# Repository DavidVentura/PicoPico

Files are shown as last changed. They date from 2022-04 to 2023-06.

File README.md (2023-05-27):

# Pico Pico

Project to attempt to create hardware for the [Pico-8](https://www.lexaloffle.com/pico-8.php).

I'd like to eventually get full game running on a ~[Raspberry Pi Pico](https://www.raspberrypi.com/documentation/microcontrollers/raspberry-pi-pico.html)~ [ESP32](https://www.adafruit.com/product/3979)

Be aware, the code will be terrible, this is a project to learn:

* C
* SDL
* Embedded
* CMake
* Lua
    * And how to adapt / modify languages
* JIT-ting ??

This project uses [z8lua](https://github.com/DavidVentura/z8lua) to implement Pico8's Lua dialect; I've whacked the original repo to make it build 
with the Pico as a target, it was all implicit casting, which I hopefully got right.

This project also gets some "inspiration" from [tac08](https://github.com/0xcafed00d/tac08/tree/master/src) - ideas for things I don't know how to solve, and the "firmware.lua" file 
for basic implementations.

## Demo

### In emulator (SDL/rawdraw backed)

https://user-images.githubusercontent.com/3650670/209883786-df8e24eb-6469-4147-87f5-97d2407c08f9.mp4

### Celeste in ESP32

https://user-images.githubusercontent.com/3650670/168416377-bf238d62-6be6-4b70-a04c-2d60ab57a269.mp4

### In Raspberry pi Pico (port abandoned, not enough RAM)

https://user-images.githubusercontent.com/3650670/166146124-06b8b223-27b1-47ac-931f-67ba8b523d9e.mp4

### On Android

https://github.com/DavidVentura/PicoPico/assets/3650670/8b1ce7c6-c577-427d-8bed-b0ab688078c9

### On 3DS

https://github.com/DavidVentura/PicoPico/assets/3650670/648f5ae0-5fe0-4eac-8bdf-cbaad8db8e8a

## Hardware

### BOM

* 1x THT Power switch [TME](https://www.tme.eu/nl/en/details/os102011ma1qn1/slide-switches/c-k/) [PDF](https://www.tme.eu/Document/b47a7178f6dd5c46f052ff087f56764e/OS_series_DTE.pdf)
* 8x SMD button [TME](https://www.tme.eu/nl/en/details/evqq2202w/microswitches-tact/panasonic/) [PDF](https://www.tme.eu/Document/7162409d248aba412c7389d402f46025/EVQQ2series.pdf)
* 1x 10k horixontal potentiometer [TME](https://www.tme.eu/nl/en/details/r0141-2-10k/single-turn-tht-trimmers/sr-passives/) [PDF](https://www.tme.eu/Document/48eb4fb11c5e0c9b1cd467745dfbcb98/R0141-2.pdf)
* 8x SMD 10k resistor
* MAX98357 I2S audio amplifier [ALI](https://www.aliexpress.com/item/1005004280540810.html?spm=a2g0o.order_list.order_list_main.11.5b1c18020Z9uMr)
* ESP32 "Wrover" with 4MB PSRAM [Amazon](https://www.amazon.de/gp/product/B07RWHK65X/ref=ppx_yo_dt_b_asin_title_o08_s00?ie=UTF8&psc=1)
* 1.77" SPI ST7735 128x160 Display (128x128 used for game, 16px for UI, 16px padding) [ALI](https://www.aliexpress.com/item/1005003797803015.html?spm=a2g0o.order_list.order_list_main.23.5b1c18020Z9uMr)

# Goals

1. ✅ Make `hello_world` work without regressions )).
    * ~All letters are white~ (lazy palette evaluation was missing a palette indirection (screen vs draw))
1. ✅ Make `rockets` fully playable (without music // complete SFX).
    * ~Points go up too fast~ (`time()` was returning millis)
1. ✅ Create some basic automated testing.
    * Tests are at `tests/`, they run one (or a few) frames and get output.
    * Need to integrate better into the project; exclusive `ifdef` for header selection
1. Make `celeste` fully playable (without music // complete SFX)
    * ~Clouds suddenly appear~ (bad rectfill types, took uint instead of int)
    * Sometimes 2 celestes appear?? mostly on level crossings
1. Make `valdi` fully playable (without music // complete SFX)
    * ~Renders offset when looking to the left~ (wasn't calculating the sprite width accordingly in `spr()`)
    * `fillp` not implemented (background)
    * ~Super slow after a few resets?~ (`gfx_line` was missing a bounds check, overwriting the delay between frames)
1. Make `awake` fully playable (without music // complete SFX)
    * Colors are super glitched, level2 is also glitched

# Basic analysis / feasibility:

Memory requirements:

* Spritesheet, at 128x128 in size = 16KB 
    * Can move to flash
* Fontsheet, at 128x128 in size = 16KB
    * Can move to flash
* Map, at 64x128 = 8 KB
    * Can move to flash
* Flags, at 2x128 = 256B
    * Can move to flash
* Sound effects, 64x84 = 5376B (~5KB)
    * Can move to flash
* Music patterns, 64x6 = 384B
    * Can move to flash
* Front buffer 128x128/2 = 8KB (x/y position -> palette)
* Back buffer 128x128x2 = 32KB (x/y position -> color, at 16bpp)
* HUD buffer 16x128x2 = 4KB
    * Can squeeze to 8x64x2 = 1KB, or even 7 sprites (896b)
* Dedicated "Game memory" = 32KB

Totals ~130KB (of which 76KB for screen buffers and game memory have to stay).

And **most importantly** 2MB for game RAM (Lua memory). This varies based on each game, but on the PICO the 264KB ran out pretty fast. There's [this thing](https://github.com/yocto-8/yocto-8/blob/main/doc/extmem.md) to use _very slow, very cursed_ external RAM. _Some_ games 

# Performance

In RPI Pico:

Running `hello_world.lua`:

* Normal: 13ms / frame; of which:
    * Lua: ~9ms / frame
    * Copying backbuffer to screen (`uint8_t`): ~4ms / frame

* Display on 2nd core: 7.5ms / frame; of which:
    * Lua: ~7ms / frame
    * ~Copying backbuffer to screen~ happens "for free" in the other core

* Multicore + overclock to 260MHz: 3.5ms/frame

In ESP32:

Celeste takes about 9ms / frame (rendering happens on the second core), including SFX

# TODO

Immediate:

* ~Get basic rendering on the Pico~
    * ~split backends properly~
* ~Read code from p8 file instead of having split files~
* ~Implement map~
* ~Implement camera~
* ~Lua dialect~ (using z8lua)
* ~Unify the build systems (Make for pc / CMake for pico)~
* ~Pre-encode the palette colors as a RGB565 `uint16_t`; makes no sense to shift them on _every pixel write_~
* ~SFX~
* ~Measure and output the correct number of samples out of the audio buffer, currently it's a (badly) guessed number.~
* ~Get reasonable audio quality out of SFX~
* Deal with warnings when building for ESP
    * ~Figure out why they don't show up when building with SDL backend~
* ~Move hardcoded pin for ESP32 to sdkconfig~
    * Extract current values for docs WIP
* Implement more complete SFX
* Generate board captures automatically
* ~Add support for short-hand print ('?"x"' == print("x"))~
* Implement fillp https://pico-8.fandom.com/wiki/Fillp
* Lua error: bad argument #1 to 'split' (string expected, got nil)
* Lua error: bad argument #1 to 'btn' (number expected, got nil)
    * z8lua considers literal circle (🅾️) to be `nil` but not ❎

Later:

* ~Clock rate on SPI?~ set to 62.5MHz; not sure if it can go higher
* Implement flash
    * cartdata command could use it
    * carts could be stored in flash instead of static data
* Investigate pushing pixels to display via DMA
    * worth it? the second core is idle anyway
* Music
* Look at optimizing lua bytecode for "fast function calls", for "standard library"
* Use headers instead of stupid ifdefs
* Enable `-Wconversion`
* Console-based UI game
    * [Virtual keyboard](https://www.lexaloffle.com/bbs/?tid=41855) [(original, no lowercase)](https://www.lexaloffle.com/bbs/?tid=4076)
    * Wifi menu
    * Cart explorer?

# Other stuff

Resources are parsed from plaintext into a header by the `to_c.py` script, this also covers converting source code to byte-code. 
Having byte-code compiled in a pre-processing stage makes parsing faster (112ms -> 18ms for a large cart), uses less memory (bytecode 
stays in flash, not necessary to load to RAM) and enables future bytecode-level optimization

## Sound

I yoinked [zepto8's synth](https://github.com/samhocevar/zepto8/blob/master/src/synth.cpp) and converted it to `fix32`; an example SFX went 
from ~25ms to ~2ms on the ESP32.

# API Support

## Graphics

| Function | Supported | Notes |
|---|---|---|
|camera |✅ | |
|circ |✅ | |
|circfill |✅ | |
|oval |✅ | |
|ovalfill |✅ | |
|clip |✅ | |
|cls |✅ | |
|color |✅ | |
|cursor |❌ | |
|fget |✅ | |
|fillp |❌ | |
|fset |❌ | |
|line |✅ | |
|pal |⚠️ |Only "draw palette" is implemented|
|palt |✅ | |
|pget |✅ | |
|print |⚠️ |Does not automatically scroll|
|pset |✅ | |
|rect |✅ | |
|rectfill |✅ | |
|sget |✅ | |
|spr |✅ | |
|sset |✅ | |
|sspr |⚠️ | |
|tline |❌ | |

## Tables

All implemented (z8lua)

## Input

`btn` implemented

## Sound

| Function | Supported | Notes |
|---|---|---|
|sfx |⚠️ | Offset is not implemented |
|music |❌ | |

## Map

All implemented

## Memory

Not implemented

## Math

All implemented (z8lua)

## Cartridge data

| Function | Supported | Notes |
|---|---|---|
|cartdata |⚠️ | Not persistent |
|dget |⚠️ | Not persistent |
|dset |⚠️ | Not persistent |
|cstore |❌ | |
|reload |❌ | |
cartdata/dget/dset are _technically_ implemented, there's no persistence layer though.

cstore/reload are not implemented.

## Coroutines

Implemented by aliasing (z8lua)

## Strings 

Implemented (z8lua)

## Values and objects

Implemented (z8lua)

# Hardware

Build something like the [PicoSystem](https://shop.pimoroni.com/products/picosystem?variant=32369546985555) ?

# Development setup

```bash
sudo apt install cmake g++ libsdl2-dev
git submodule update --init
mkdir pc_pico && cd pc_pico
cmake -DBACKEND=PC ..
```

# Development on RP2040 (without a second Pico running OpenOCD)

Add this block to a udev rule (adjust the paths to point to this repo)
```
SUBSYSTEM=="block", ATTRS{idVendor}=="2e8a", ATTRS{idProduct}=="0003", ACTION=="add", SYMLINK+="rp2040upl%n"
SUBSYSTEM=="block", ATTRS{idVendor}=="2e8a", ATTRS{idProduct}=="0003", ACTION=="add", RUN+="/home/david/git/luatest/udev_build.sh rp2040upl%n"
```

Then having an open minicom shell 
```
sudo minicom -b 115200 -D /dev/ttyACM1
```

you can press `r` on it to reboot into mass-storage mode; which will trigger the udev rules after a second or so.

# Tests

There's a CMake backend (TEST) that you can use with `cmake -DBACKEND=TEST`; in that backend, the command `make test` will run some tests.

Some of the tests are for the internal APIs, and are written in C. Generally though, most tests should be written as p8 cartridges and placed in `tests/regression/*.p8`.

Internal API tests usually compare the output with some expected, known-good frontbuffer values (a "screenshot").
Whenever these need to change, the specific test can be re-run with the environment variable `OVERWRITE_TEST_BUF` set to any value.
This will overwrite `tests/data/buf_*.bin`. To look at these buffers, you can use the command `bin_to_png`.

```
> make test
Running tests...
Test project /Users/tati/git/PicoPico/tests_build
    Start 1: test_hello_world
1/5 Test #1: test_hello_world .................   Passed    0.03 sec
    Start 2: test_hud
2/5 Test #2: test_hud .........................   Passed    0.03 sec
    Start 3: test_menu
3/5 Test #3: test_menu ........................   Passed    0.03 sec
    Start 4: test_primitives
4/5 Test #4: test_primitives ..................   Passed    0.03 sec
    Start 5: test_regression
5/5 Test #5: test_regression ..................   Passed    0.03 sec

100% tests passed, 0 tests failed out of 5

Total Test time (real) =   0.16 sec
```

```
> ./test_regression
Testing regression_api_p8
  test_map_no_args                        [ OK]
  test_print_p8scii_color                 [ OK]

Testing regression_asan_p8
  test_sspr_same_size_is_maintained       [ OK]
  test_circ_top_left_edge                 [ OK]

Testing regression_other_p8
  test_nothing                            [ OK]
```

# Useful links

* [Easy intro to Embedding lua](https://lucasklassmann.com/blog/2019-02-02-how-to-embeddeding-lua-in-c/#example-of-error-handling)
* [Lua 5.2 Manual](https://www.lua.org/manual/5.2/manual.html)
* [Storing data in flash](https://kevinboone.me/picoflash.html?i=1)
* [Udev rule to copy build automatically](https://forums.raspberrypi.com/viewtopic.php?t=333160)
* [Getting started on basic Pico8 Gamedev](https://lukemerrett.com/getting-started-with-pico-8/)
* [GameTiger, another Pico-based console](https://github.com/codetiger/GameTiger-Console)
* [Espressif docs](https://docs.espressif.com/projects/esp-idf/en/latest/esp32/get-started/linux-macos-setup.html)
* [Importing custom 3D models into kicad](https://happyrobotlabs.com/posts/tutorials/tutorial-3d-kicad-parts-using-openscad-and-wings3d/)

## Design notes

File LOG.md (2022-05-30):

# Journal

Partly live-ramblings and partly back-filled from git log

### Wed Apr 27

I saw some news about Raspberry Pico and Pico8 on the same day and got the idea to implement Pico8-on-Pico.

First thoughts:

* Should run _some_ games without modifying the carts
* Should run on PC for easier debugging of "console" logic

To run on PC, I looked around a bit and decided to go with SDL; started following [Lazy Foo's tutorials](https://lazyfoo.net/tutorials/SDL/index.php)

Got a first basic screen with textures loading on SDL, and some colored pixels rendering on the Pico. This verison used CMake for the Pico (straight off the tutorial) and Make for PC

### Sat Apr 30

"Hello world" demo was running **really** slow, mostly because it was sending 1 byte at a time; replace ST7735 call to instead send the entire buffer directly.

Added timing on frames to "benchmark" some approaches a bit (ms resolution).

### Sun May 1

Got really annoyed at the dev cycle; to get a build onto the pico I had to:
* unplug the pico
* press bootsel while re-plugging the pico
* mount the pico
* drag & drop the new files

All of this.. to see my code crash slightly farther down the line; so I added into the input polling function, a mechanism to reset into usb mode when pressing "r" over usb-uart.. at least I could skip the "unplug, press, replug" part.  
Afterwards I also added a udev script (committed to the repo) that automatically mounts & copies the latest build over. This means that pressing "r" over UART will end up with a new build in the pico in ~8s. Need to look at OpenOCD.

Pushing a screenful of pixels takes about ~12ms with the current settings; so with logic taking ~9ms on "Hello world" demo, there's a hard limit of ~40FPS.
This sucks; games more complicated than "hello world" will spend more time on their game logic, dropping FPS down further.

Moved rendering to second core. This was _so easy_, maybe 4 lines of code; and it improved FPS dramatically (obviously -- now the rendering doesn't take time from the game cycle).
However.. the screen flashed like a maniac, having games call `cls()` while the buffer is being pushed to the screen will cause this )).

Split the screen buffer into front/backbuffer so the game can muck with the front buffer all it wants, and the copy of front->back buffers happens only on `flip()`.

Inlined `put_pixel` for an easy ~0.5ms faster frame

### Mon May 2

Add a "stdlib" to lua -- implementing pico8 special builtins

Get PC target building on CMake.

### Tue May 3

Integrate [z8lua](https://github.com/samhocevar/z8lua) into the build. It took me HOURS, as there was a lot of implicit casting that works on 64bit platforms, but not when targetting the pico.

Then spend many more hours debugging why the new Lua would work on PC and crash on Pico. Turns out `luaL_checkversion` returns errors, and the error was quite clear:

```
bad conversion number->int; must recompile Lua with proper settings
```

I'd forgotten some type casts -- I ended up changing the types for `LUA_INT32` and by extension `LUA_UNSIGNED` (this one is defined based on `LUA_INT32`). This made the interpreter work on the Pico.

This took many experiments; so after adding error handling on Lua init; I added some code to trigger "wait for re-flash" if Lua failed to init.

Another huge pain in the ass: I had a silly mistake in the `stdlib.lua` file.. and wasn't checking for errors when executing it. So the games could not access anything defined in it. Added error handling.

Still don't know how to use CMake, so added an `OPTION` to selectively build for Pico or PC. It 'works' but I need to clean the CMakeCache.txt file every time I switch.

Ran out of memory when loading "larger" games. My calculations must be off - I thought I had more space to spare. Start thinking about how to compress static data.

Remove hardcoded screen dimensions; this was the cause of ENDLESS bugs

### Wed May 4

Implement a simple RLE algorithm

|file			| initial size	| encoded	|
|---|---|---|
|artifacts/font.lua	| 16513		|4898		|
|examples/map.p8	| 3662		|807		|
|examples/btnp.p8	| 374		|375		|
|examples/movement.lua	| 287		|288		|
|examples/tennis.p8	| 21006		|3700		|
|examples/dice.p8	| 25610		|7924		|
|examples/hello\_world	| 4220		|1115		|
|total			| 68010 	|19107 (~0.3x)	|

Where you see size increase by 1 is because I always add a NULL byte at the end of the content, for easier parsing.

The algorithm is fairly simple, and strongly abuses one constraint in the input: every byte must be valid ASCII (ie: <128). This means that every byte in the input **must** have its highest bit unset.

With this in mind, the algorithm is:

* Read 1 byte
    * If highest bit is set: `count = next byte`
    * If highest bit is unset: `count = 1`
* Place the read char `count` times in output buffer
* Repeat

However! the code has to special-case the value where the repetition count is `10` (that is `\n`); as this would confuse the "read file based on newlines" algorithm. The "special" value `0xFF` is used in this case.

Realized that copying the backbuffer to screen takes 11.5ms because the SPI clock frequency is set to 30MHz. Setting it to 62.5MHz (number from `GameTiger` repo) makes the transfer take ~4ms.

# Thu May 5

I ran out of memory again, when trying to run "Rockets!". After a lot of poking around with the linker map, I realized that the static assets (cart data, font, stdlib) weren't declared as `const`! Making them `const` released ~50KB.  
I also looked for some easy memory and noticed I was allocating a static 32KB buffer for the code _text_ which is not used after Lua initializes the VM; so I made that dynamic memory and freed it after using it. Easy 32KB.
I'll probably release another 10KB later.

Struggling with the performance of `Rockets!`, seems that manually drawing rotated sprites, pixel by pixel, is _slow_. Not sure why, these ~400 calculations take ~30ms.

Will first look at converting the SPI transfers to 16bit wide (been pending for a bit..) and maybe after use the new 240x240 screen I got

# Sun May 8

Gave up on running on RP2040 after realizing there was _no way_ I could fit the promised Lua space for _game memory_ (2MB) anywhere.  
Went and got an ESP32 "WROOM32" which has 4MB (mega _bytes_) of SPIRAM (slow), but magic in the MMU makes it cache, so could be alright. Ordered one, and starting hacking on a spare ESP32 I had.

Getting the build and compiler going was a nightmare; couldn't get the magic CMake functions to include the Lua sources so it kept failing to link.

Eventually, got it going and had another nightmare: the display would randomly not turn on. Seems like it was a timing issue, as fiddling with the BLK randomly on reboot would get it going.  
When the new WROOM32 arrived, the issue mysteriously went away.

The docs on the ESP are nowhere as clear as the RP2040 docs; I kept having failures to do SPI transfers in bulk and had to chop them off in small bits. It was [right here](https://espressif-docs.readthedocs-hosted.com/projects/esp-idf/en/latest/api-reference/peripherals/spi_master.html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) in the docs though, that the default limit is _4094_ bytes. Still unsure why it wants to `malloc` its own chunk of memory per transaction, instead of letting me give it one (the backbuffer exists _for this reason_).

After this was "running" (a _lot_ of the build is hacked / chopped), I went back to the "rockets" example, as it kept having performance issues on the Pico, with ~20-30ms to draw each rotated sprite. In the ESP this is a bit faster but still very slow (~14ms).  
Biggest problem is that it does 400 inner loops _per frame, per sprite_ to draw the rotated sprites.  The only way I see something like this working is to JIT this _somehow_, but that seems _so_ hard.

Some silly performance notes:

The code for st7789, as written, would take ~500ms to render a full screen of solid color. Replacing that code with a single SPI call takes ~5-7ms. [This doc](https://austinmorlan.com/posts/embedded_game_programming_3/) helped me a bit on getting things going.

Calling `put_pixel` 50k times:

* At `-O2`: 2ms
* At `-Og`: 7ms
* At `-O0`: 10ms
* At `-Os`: 25ms

maybe `-Os` is ignoring the `inline` ?

Still can't get the SPI data transfer to be LSB to avoid having to flip endianness on the front->backbuffer copy. Can probably do it anyway when writing to the FB..

[ESP32 SPIRAM speed](https://www.esp32.com/viewtopic.php?t=13356) ~20MB/s, more if hitting the cache.

# Mon May 9

Merged ESP32 branch (breaking other targets in the process). Gave up on trying to scale up the game to my 1.33" 240x240 display; bought a 160x128 1.44" display (will have to futz around with the other driver.. again).  
But the image at least should be a lot larger & clearer.

Mostly gave up when calculated that at 40MHz, I could do over (1-bit) SPI, at MOST 40FPS, if the core did nothing but transfer data.. yet I would need to dynamically stretch the image on every frame, as there's not enough space for a 240x240x2 
framebuffer in DRAM (can use PSRAM, but that's slower). Alternative is to find and use a 8-bit SPI display, but still, not great to have to resize the image on every frame.

Thinking about audio, but that sounds super complicated so will leave that in the background and keep reading.

Found [this report](https://nymphium.github.io/pdf/opeth_report.pdf) about lua bytecode optimization and really want to look into doing something like it. Particularly lowering the cost of a function call for the "standard library"

After a couple of minutes of executing the `celeste` level; the same corruption appears on the map (a couple of black pixels); not sure why yet.

Want to configure a joystick / buttons to actually _use_ the console, but the ADC always read either 0 or 4095 and the multimeter is broken ((

# Wed May 10

Fixed the build so that all platforms can build in one go, without having to comment out `#define`s; also moved most of the code that was duplicated (`gfx_*`) to be shared, managed to delete _a bunch_ of code.

Curious about performance implications of all the current bit shifting done to render (given that each color on the palette is a `uint8_t[3]`). Starting point; in celeste, the frames take:

```
Frame avg 16200µs
Frame avg 16159µs
Frame avg 16239µs
Frame avg 16243µs
Frame avg 16170µs
Frame avg 16144µs
Frame avg 16311µs
Frame avg 16240µs
```
(Average: 16213)

Moving average, over 100 frames.

And after changing the palette lookup per pixel:

```
Frame avg 13876µs
Frame avg 13849µs
Frame avg 13963µs
Frame avg 14121µs
Frame avg 13989µs
Frame avg 13923µs
Frame avg 13892µs
```
(Average: 13944)

16% faster!! that's a nice, easy win.

# 13 May

Got SFX working! Struggled to understand the basics of synths but [this video](https://www.youtube.com/watch?v=OSCzKOqtgcA) helped quite a bit.

Getting SDL going also took a while; combination of sample rates and endianness blasted my ears more than necessary.

When the emulator sounded OK, I ran it on the ESP32 without any output configured and saw that the simplest SFX took ~25ms to calculate (sure, the sound lasts like 400ms, but I don't want 10% of the CPU time to go to SFX!).

I know the ESP32 has an FPU, which means floating point calculations are not _terribly_ slow, but they are not as fast as integer arithmethic; so made some optimizations: turns out `fmodf(advance, 1.f)` takes _8_ extra milliseconds than  `advance - truncf(advance)` (over ~11 thousand calls).  This already brought ~25ms to ~17ms.  Moved quite some constants to be static and some calculations out from the inner loop, and the execution time dropped to ~4.5ms(!)

Still, the [Performance guide](https://docs.espressif.com/projects/esp-idf/en/latest/esp32/api-guides/performance/speed.html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) on ESP32 says

>  Even though ESP32 has a single precision hardware floating point unit, floating point calculations are always slower than integer calculations. If possible then use fixed point representations [...]

and I already am linking `fix32` for Lua.. so converted the synth to use fixed point and that made it at least twice as fast (down to ~2ms).

# 14 May

Rewrote the sounds pipeline -- it used to generate ALL the samples for an SFX on demand, and fill HUGE buffers with it.  
Now, based on a lot of reading (which is greatly summarized [here](https://atomic14.com/2021/04/20/esp32-i2s-dma-buf-len-buf-count.html)) I've changed the pipeline to only generate samples on demand (when the DMA buffers are empty) -- currently that is ~20ms worth of audio. This simplified the code a lot, and now it actually works without pops

# 17 May

Start looking at Lua performance overhead:

Benchmark code:
```lua
start = t()
for i=1,32000 do
      noop(i)
end
endt = t()
printh("32k x noop took ".. endt-start)
```
- 32.000 noop calls (takes 1 number and returns it) = 122ms

meaning, 1.000 calls = 3.8ms. **This caps the calls per frame at 8684 without doing any work**.

Per iteration; the bytecode looks like

```
5	[2]	GETTABUP 	4 0 -3	; _ENV "noop"
6	[2]	MOVE     	5 3
7	[2]	CALL     	4 2 1
```

Same code in C (with -O0) takes ~6ms:

```c
#pragma GCC push_options
#pragma GCC optimize ("O0")
int _noop(int arg) {
    return arg;
}
void bench_me() {
    uint32_t bstart = now();
    int res = 0;
    for (uint16_t i=0; i<32000; i++) {
        res = _noop(5);
    }
    printf("Benchmark took %d; result is %d\n", now()-bstart, res);
}
#pragma GCC pop_options
```

Approximately, 20x faster is the maximum we can get to.

# 18 May

On first pass of ["Fast C Calls"](https://github.com/DavidVentura/z8lua/commit/201aa808ca1e0b0529a6d9af0c80307fec263d92):

> 32k x noop took 94ms

1000 calls = 2.9ms; new code takes 77% of the time as the previous one;

the bytecode hasn't changed; so 

```
5	[2]	GETTABUP 	4 0 -3	; _ENV "noop"
6	[2]	MOVE     	5 3
7	[2]	CALL     	4 2 1
```

this way, `noop` is _still looked up for each call_; as the function tag is embedded in the function itself (which is stored in `_ENV`)

this is faster, yes, but not _really_ fast

Calling a function that does a _small_ amount of work:

```lua
start = t()
for i=1,32000 do
      fast_floor(i+0.5)
end
endt = t()
printh("32k x fast_floor took ".. endt-start)

start = t()
for i=1,32000 do
      flr(i+0.5)
end
endt = t()
printh("32k x flr took ".. endt-start)

```

> 32k x fast_floor took 99ms
> 32k x flr took 145ms

Not really sure about these results.. the fast call went up by 5ms (I assume, calculating how to floor the number), but the regular call doesn't take 5 ms more than the slow noop.. takes 23ms more.

I think the real improvement for this would be to add a new opcode (ie: FASTCALL) that'd embed the function ID in a byte or something. I only want to "accelerate" a handful of calls (<30) so capping at 255 is not a problem.

This all kinda started by looking again at `Rockets!` which used to take ~30ms to draw each sprite (it calculates rotation _every frame_)

With the "regular" `flr` calls, drawing 5 sprites consistently takes 71ms, and with the fast calls it consistently takes 65ms. It's a nice 9% win, but still _really_ far from hitting the <30ms mark to make the game playable.

This is the function that's so slow:

```lua
function spr_r(s,x,y,a,w,h)
	sw=(w or 1)*8
	sh=(h or 1)*8
	sx=(s%8)*8
	sy=flr(s/8)*8
	x0=flr(0.5*sw)
	y0=flr(0.5*sh)
	a=a/360
	sa=sin(a)
	ca=cos(a)
	for ix=sw*-1,sw+4 do
		for iy=sh*-1,sh+4 do
			dx=ix-x0
			dy=iy-y0
			xx=flr(dx*ca-dy*sa+x0)
			yy=flr(dx*sa+dy*ca+y0)
			if (xx>=0 and xx<sw and yy>=0 and yy<=sh-1) then
				pset(x+ix,y+iy,sget(sx+xx,sy+yy))
			end
		end
	end
end
```

`sw` and `sh` are always 8; so both loops go from -12 to 12 (=576 iterations for the inner loop). This is _per sprite_ and up to 5 sprites can be live at any point in time.

If you know about lua performance, you already know what the _biggest_ problem is here, but it is very obvious when looking at bytecode; this is the inner loop:

```
	50	[569]	GETTABUP 	14 0 -8	; _ENV "x0"
	51	[569]	SUB      	14 9 14
	52	[569]	SETTABUP 	0 -18 14	; _ENV "dx"
	53	[570]	GETTABUP 	14 0 -10	; _ENV "y0"
	54	[570]	SUB      	14 13 14
	55	[570]	SETTABUP 	0 -19 14	; _ENV "dy"
	56	[571]	GETTABUP 	14 0 -7	; _ENV "flr"
	57	[571]	GETTABUP 	15 0 -18	; _ENV "dx"
	58	[571]	GETTABUP 	16 0 -14	; _ENV "ca"
	59	[571]	MUL      	15 15 16
	60	[571]	GETTABUP 	16 0 -19	; _ENV "dy"
	61	[571]	GETTABUP 	17 0 -12	; _ENV "sa"
	62	[571]	MUL      	16 16 17
	63	[571]	SUB      	15 15 16
	64	[571]	GETTABUP 	16 0 -8	; _ENV "x0"
	65	[571]	ADD      	15 15 16
	66	[571]	CALL     	14 2 2
	67	[571]	SETTABUP 	0 -20 14	; _ENV "xx"
	68	[572]	GETTABUP 	14 0 -7	; _ENV "flr"
	69	[572]	GETTABUP 	15 0 -18	; _ENV "dx"
	70	[572]	GETTABUP 	16 0 -12	; _ENV "sa"
	71	[572]	MUL      	15 15 16
	72	[572]	GETTABUP 	16 0 -19	; _ENV "dy"
	73	[572]	GETTABUP 	17 0 -14	; _ENV "ca"
	74	[572]	MUL      	16 16 17
	75	[572]	ADD      	15 15 16
	76	[572]	GETTABUP 	16 0 -10	; _ENV "y0"
	77	[572]	ADD      	15 15 16
	78	[572]	CALL     	14 2 2
	79	[572]	SETTABUP 	0 -21 14	; _ENV "yy"
	80	[573]	GETTABUP 	14 0 -20	; _ENV "xx"
	81	[573]	LE       	0 -22 14	; 0.0 -
	82	[573]	JMP      	0 24	; to 107
	83	[573]	GETTABUP 	14 0 -20	; _ENV "xx"
	84	[573]	GETTABUP 	15 0 -1	; _ENV "sw"
	85	[573]	LT       	0 14 15
	86	[573]	JMP      	0 20	; to 107
	87	[573]	GETTABUP 	14 0 -21	; _ENV "yy"
	88	[573]	LE       	0 -22 14	; 0.0 -
	89	[573]	JMP      	0 17	; to 107
	90	[573]	GETTABUP 	14 0 -21	; _ENV "yy"
	91	[573]	GETTABUP 	15 0 -4	; _ENV "sh"
	92	[573]	SUB      	15 15 -2	; - 1.0
	93	[573]	LE       	0 14 15
	94	[573]	JMP      	0 12	; to 107
	95	[574]	GETTABUP 	14 0 -23	; _ENV "pset"
	96	[574]	ADD      	15 1 9
	97	[574]	ADD      	16 2 13
	98	[574]	GETTABUP 	17 0 -24	; _ENV "sget"
	99	[574]	GETTABUP 	18 0 -5	; _ENV "sx"
	100	[574]	GETTABUP 	19 0 -20	; _ENV "xx"
	101	[574]	ADD      	18 18 19
	102	[574]	GETTABUP 	19 0 -6	; _ENV "sy"
	103	[574]	GETTABUP 	20 0 -21	; _ENV "yy"
	104	[574]	ADD      	19 19 20
	105	[574]	CALL     	17 3 0
	106	[574]	CALL     	14 0 1
```

The issue here are all those `GETTABUP` (`get table upvalue`) which are looking up the _global variables_ in every call. Usually, the way to have this work faster is by declaring each variable `local` so they'll be in the function's registers. By changing all the variables to `local`, this is the generated bytecode

```
	36	[569]	SUB      	23 18 10
	37	[570]	SUB      	24 22 11
	38	[571]	GETTABUP 	25 0 -3	; _ENV "flr"
	39	[571]	MUL      	26 23 14
	40	[571]	MUL      	27 24 13
	41	[571]	SUB      	26 26 27
	42	[571]	ADD      	26 26 10
	43	[571]	CALL     	25 2 2
	44	[572]	GETTABUP 	26 0 -3	; _ENV "flr"
	45	[572]	MUL      	27 23 13
	46	[572]	MUL      	28 24 14
	47	[572]	ADD      	27 27 28
	48	[572]	ADD      	27 27 11
	49	[572]	CALL     	26 2 2
	50	[573]	LE       	0 -10 25	; 0.0 -
	51	[573]	JMP      	0 15	; to 67
	52	[573]	LT       	0 25 6
	53	[573]	JMP      	0 13	; to 67
	54	[573]	LE       	0 -10 26	; 0.0 -
	55	[573]	JMP      	0 11	; to 67
	56	[573]	SUB      	27 7 -1	; - 1.0
	57	[573]	LE       	0 26 27
	58	[573]	JMP      	0 8	; to 67
	59	[574]	GETTABUP 	27 0 -11	; _ENV "pset"
	60	[574]	ADD      	28 1 18
	61	[574]	ADD      	29 2 22
	62	[574]	GETTABUP 	30 0 -12	; _ENV "sget"
	63	[574]	ADD      	31 8 25
	64	[574]	ADD      	32 9 26
	65	[574]	CALL     	30 3 0
	66	[574]	CALL     	27 0 1
```

With this change, rendering 5 sprites goes from the ("optimized") 65ms/frame to **29ms/frame**. 21 extra lookups * 576 inner loops = 12096 calls.. which acording to my original benchmarking (if these were function calls) is ~45ms.

So, maybe optimizing opcodes for fastcalls is not the thing that will bring the biggest gains; maybe a bytecode optimizer would be better.

Performing some manual optimizations in the lua code (declaring a local copy of `pset` `sget` `flr` and lifting calculations outside the inner loop) brought the frame time to **23ms**; a 26% improvement; and _almost_ perfectly playable.

TODO: fastcall `sget` and `pset` to test the impact (12k calls each ?)

Interesting optimizations:

* Localizing global accesses (`sin` shouldn't be loaded from `_ENV`)
* Fast builting calls (`sin` should be called cheaply)
* [Loop hoisting](https://en.wikipedia.org/wiki/Loop-invariant_code_motion)

# 20 May

Still going on about performance; now on trig functions:

Baseline

> 32k x c sin floating took 548ms

Optimizing calls into the "regular fastcalls" (ie: still looking up via _ENV on every call)

> 32k x fast sin floating took 718ms
> 32k x slow sin floating took 735ms

This makes 32k calls, 20ms faster.. in practice this is not going to make a difference

Still struggling to figure out how to emit bytecode that's aware of the builtins

Optimizing `sin`:

Using [fixed point calculations](https://www.nullhardware.com/blog/fixed-point-sine-and-cosine-for-embedded-systems/) for `sin`:

> 32k x c sin fixed 	  took  50ms
> 32k x fast sin fixed 	  took 107ms
> 32k x slow sin fixed 	  took 135ms
> 32k x slow sin floating took 735ms

Now this is _a lot_ faster! ~7x faster `sin` / `cos` calls

# 22-23 May

Wrote/Adapted a bytecode parser in python

# 25 May

Thinking about bytecode optimization, tried to write a "too-hard" optimization from the start and failing.

Easy optimizations to start with:

* Make all globals, "local scoped globals"
    * Declare them `local` at the root chunk
    * Adjust upvals on all functions
    * Replace {GET,SET}TABUP with {GET,SET}UPVAL
* Remove unused constants (that will happen when removing {GET,SET}TABUP)
* Remove unnecessary loads when there's no change in the registers
    * ```
	[018] [32]   GETTABUP : 6 0 -7; _ENV "flr"
	[019] [32]   GETTABUP : 7 0 -1; _ENV "sw"
	[020] [32]        MUL : 7 -9 7; (L)R(7) := K(9) * R(7)
	[021] [32]       CALL : 6 2 2
	[022] [32]   SETTABUP : 0 -8 6; _ENV "x0"
	[023] [33]   GETTABUP : 6 0 -7; _ENV "flr"
     ```
     in this case,  `GETTABUP : 6 0 -7; _ENV "flr"` is executed twice, and nothing writes to `R(6)` between them

# 28 May

Spent a long while getting a MAX98357 chip (I2S audio) to work. I kept getting "buzzing" sound instead of anything, even when memory dump of the waveforms gave me the same numbers as what I'd get on my SDL backend.

Mucked around with endianness; channel format; sample depth; timing. No dice. In the end, It's because I was using a 0.5W speaker with a 3W (max) amplifier. A 160Ohm resistor in series with the speaker made it work perfectly.

# 30 May

I am starting to think optimizing the bytecode will be fruitless; the "problematic" calculation-heavy routine from Rockets! still takes up to 30ms/frame after optimization. I manually converted that function to be a regular C function
and the time per frame dropped to 5ms; where 3.5-4 of those are spent drawing the map.

Got a _very bad, very simplistic_ code emitter for a Lua parser. Will see how it goes; main concerns are:

* Variable scoping
* Closures
* Co-routines
* Dynamic types

but it seems more "tractable" to let GCC optimize code, and a lot easier to get started. Although it's a lot more work to get a game into a playable state.

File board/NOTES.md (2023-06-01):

v2 issues:
- RX/TX to usb-serial chip inverted

v2 notes:
- "wrong" footprint for display
  - used the "connector" footprint but soldered...
  - should've used the solderable pinout (wider) or a connector..
- audio:
  - using resistor instead of voltage divider
  - shoddy audio idea of soldering pcb on pcb
  - direct soldering MAX98357 SKETCH
  - volume control (potentiometer) too far from edge
  - volume control footprint loose, no metal on mechanical holes
- testpoints very small
- labels very small
- battery JST different
- usb-micro not usb-c
- "jumpers" for display fuckups:
    - too close (side-by-side)
	- too large footprint for easy bridging? (MB)
- BUY STENCIL

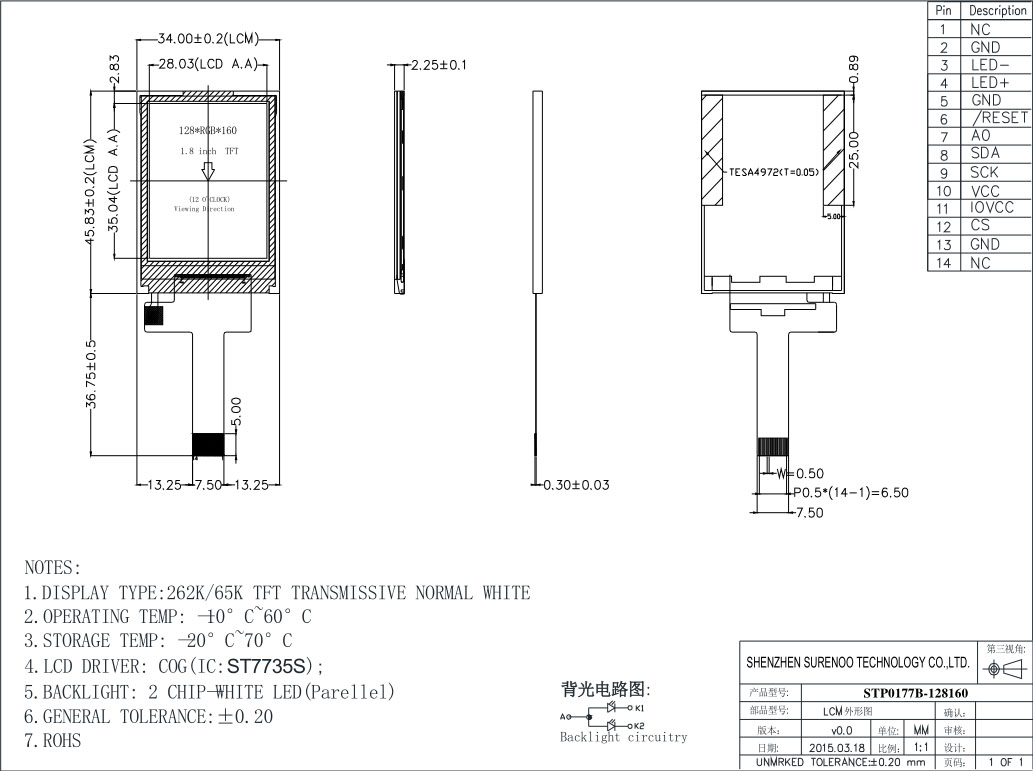
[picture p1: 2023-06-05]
board/datasheets/display.jpg

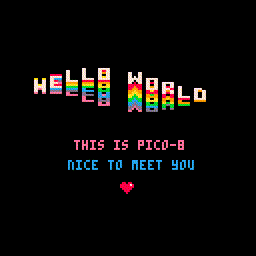
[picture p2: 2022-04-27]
artifacts/hello_world.gif

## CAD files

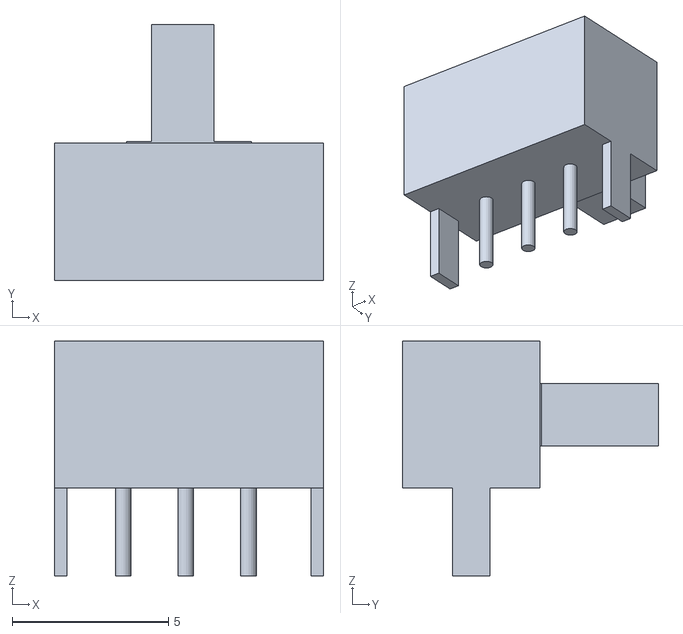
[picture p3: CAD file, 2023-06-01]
board/3dmodels/power_switch.stl
8.60 x 8.20 x 7.50

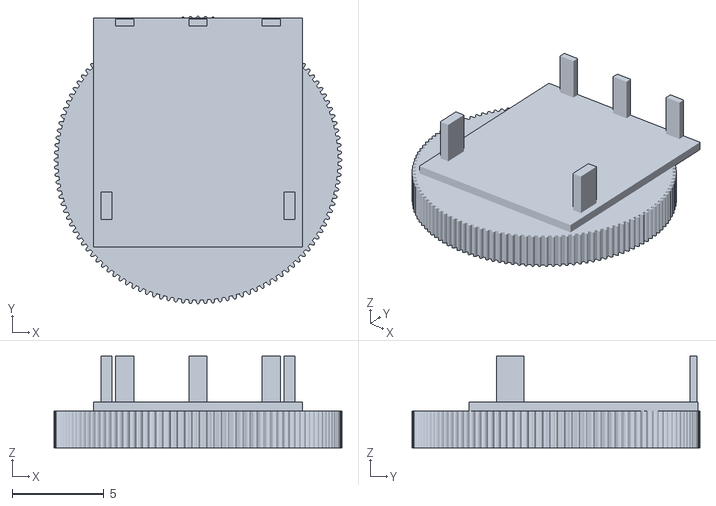
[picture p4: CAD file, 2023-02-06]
board/3dmodels/volumewheel.stl
15.7 x 15.7 x 5.00

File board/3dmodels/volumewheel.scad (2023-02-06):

pi=3.141592;
$fn=16;
module tooth(pitch){
	translate([0,0,0])scale([2,1,1])circle(pitch/2,$fn=24);
	}

module gear2d(teeth,pitch,clearance){
		union(){
			translate([0,0,0])circle(((pitch*teeth)/pi)-clearance,$fn=100);
			for(n=[1:teeth]){
				rotate([0,0,(360/teeth)*n])
				translate([(pitch*teeth)/pi,0,0])tooth(pitch*1.1);
			}
		}
	}
    
    
module pin(factor=1) {
PIN_HEIGHT=2.5;
color("silver")
cube([1*factor, 0.4*factor, PIN_HEIGHT], center=true);
}

GEAR_HEIGHT=2;
color("black")
difference() {
linear_extrude(height=GEAR_HEIGHT, center=true,convexity=10,twist=0,slices=1)
gear2d(teeth=120,pitch=0.2,clearance=0);
cylinder(h=2.1, r=2, center=true);
}

// base
color("silver")
translate([0, 1.5, 1.25])
cube([11.4, 12.5, 0.5], center=true);

// mechanical
translate([-5, -2.5, 2.75])
rotate([0,0,90])
pin(factor=1.5);


translate([5, -2.5, 2.75])
rotate([0,0,90])
pin(factor=1.5);

// pins

translate([-4, 7.5, 2.75])
pin();
translate([0, 7.5, 2.75])
pin();
translate([4, 7.5, 2.75])
pin();

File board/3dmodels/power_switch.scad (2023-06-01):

$fn=20;
PIN_HEIGHT=2.8;
PIN_SPACING=2;

// main body
color("silver")
cube([8.6, 4.4, 4.7], center=true);

// switch
color("black")
translate([1-2*$t, 4, 0])
rotate([0, 90, 0])
cube([2.0, 4.0, 2.0], center=true);

// switch displacement area
color("gray")
translate([0, 2.2, 0])
rotate([0, 90, 0])
cube([2.0, 0.1, 4.0], center=true);

// mechanical pins
color("darkgray")
translate([-8.6/2+0.4/2, 0, -(PIN_HEIGHT/2)-(4.7/2)])
cube([0.4, 1.2, PIN_HEIGHT], center=true);

color("darkgray")
translate([8.6/2-0.4/2, 0, -(PIN_HEIGHT/2)-(4.7/2)])
cube([0.4, 1.2, PIN_HEIGHT], center=true);

// electrical pins
color("darkgray")
translate([-8.6/2+0.4/2+PIN_SPACING*1, 0, -(PIN_HEIGHT/2)-(4.7/2)])
cylinder(r=0.25, h=PIN_HEIGHT, center=true);
color("darkgray")
translate([-8.6/2+0.4/2+PIN_SPACING*2, 0, -(PIN_HEIGHT/2)-(4.7/2)])
cylinder(r=0.25, h=PIN_HEIGHT, center=true);

color("darkgray")
translate([-8.6/2+0.4/2+PIN_SPACING*3, 0, -(PIN_HEIGHT/2)-(4.7/2)])
cylinder(r=0.25, h=PIN_HEIGHT, center=true);

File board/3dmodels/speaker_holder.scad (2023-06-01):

$fn=35;
OUT_SPKR_DIAM=10;
IN_SPKR_DIAM=8;
PAD=2;

difference() {
    cube([OUT_SPKR_DIAM+PAD, OUT_SPKR_DIAM+PAD, 0.5], center=true);
    
    translate([0, 0, 0.151])
    cylinder(h=0.2, r=OUT_SPKR_DIAM/2, center=true);
    cylinder(h=0.51, r=IN_SPKR_DIAM/2, center=true);
    
    for(x= [-1, 1]) {
        for(y= [-1, 1]) {
            translate([(OUT_SPKR_DIAM+PAD/2)/2*x-x, (OUT_SPKR_DIAM+PAD/2)/2*y-y, 0])
            cylinder(h=1.1, r=1, center=true);
        }
    }
}

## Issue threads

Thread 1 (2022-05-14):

Can you please share the reasons for moving from RP2040 Chip to ESP32

codetiger, 2022-05-14:
Hi,
This is a wonderful project and I would like to know more details about why you have abandoned the support for RP2040 chip. Some reasons I can think of are listed below.

1. Lua overheads in calculations.
2. Memory limitations (If my understanding is correct, Pico-8 has only 64KB of memory addressing. If so why is it hard to fit in 264KB RAM that RP2040 has?)
3. Framerate issues?
4. Is the float point calculations slowing down?

I am able to render 3D model with 5k triangles on to a 240x240 screen. using DMA and other features of the chip and it runs at 17 FPS. I am not loosing my hopes . :)

DavidVentura, 2022-05-14:
Hi

I had the exact same idea initially; there's indeed 64KB of "machine memory" (with 32KB of scratch and 32KB affecting console state).. but there's also [this](https://pico-8.fandom.com/wiki/Memory#Lua_Memory) -- you can allocate up to **2MB** of Lua objects; ie: create a table with 20000 entries

Everything else can fit in memory, if barely, but the game-object memory won't.

The "abandoning" is a bit strong -- if you look at the `pico_backend.c` -- it is very small, at the moment the only thing missing from it is a way to play SFX, the rest works, so you can give it a shot

codetiger, 2022-05-16:
I am thinking of a precompiled Lua code instead of real time interpreting. This should allow us to store the Lua memory 2mb in flash storage. Does it make sense?

DavidVentura, 2022-05-16:
Pre-compiling would help a bit; it is in fact something I'm thinking about -- however you can always do this

```lua
function f()
        t = {}
        for var=1,100000 do
                t[var] = 5
        end
end            

f()

```

and it won't execute to completion on the Pico, there's no RAM to keep the table `t`

DavidVentura, 2022-07-24:
Hey!
This does not currently work well, partly because it is incomplete and partly because I don't know enough about C++ to generate code properly, but I've started a Lua to C++ compiler here: https://github.com/DavidVentura/lua-but-worse

Closed 2023-01-06.

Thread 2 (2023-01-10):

Double Celeste issues

AndrewMc1, 2023-01-10:
Hello, not necessarily an issue. Just a note that the pico8 core that runs on the TrimUi had similar issues to the ones that you've described. Double Celeste characters, no music but sound effects. However, it has subsequently been fixed so the fix may also work for you.  Here's a link https://github.com/liartes/retro8/releases

Also I have an Odroid Go clone, that utilises an ESP32. Do you think you code would work with the Retro-Go custom firmware by  Ducalex?   https://github.com/ducalex

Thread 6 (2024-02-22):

DOWN KEY(GPIO0) doesn't work

jd3096-mpy, 2024-02-22:
This ia an amazing project!
But I found that  DOWN KEY(GPIO0) doesn't work, I tried other GPIOS like GPIO13 23 35,it still don't work,how tho slove this problem?
I found the key setting in sdkconfig
`#
# Controller configuration
#
CONFIG_GPIO_LEFT=13
CONFIG_GPIO_RIGHT=12
CONFIG_GPIO_UP=34
CONFIG_GPIO_DOWN=0
CONFIG_GPIO_A=32
CONFIG_GPIO_B=33
CONFIG_GPIO_SELECT=0
CONFIG_GPIO_START=0
# end of Controller configuration`

And can this project connect to wifi and run PICO8 splore?
Thanks a lot.

DavidVentura, 2024-02-22:
Not sure what's up with the config that it's not getting picked up - this does work on my demo PCB. Do you have external pullups on you button?

Splore is not yet supported, but I have plans to add support

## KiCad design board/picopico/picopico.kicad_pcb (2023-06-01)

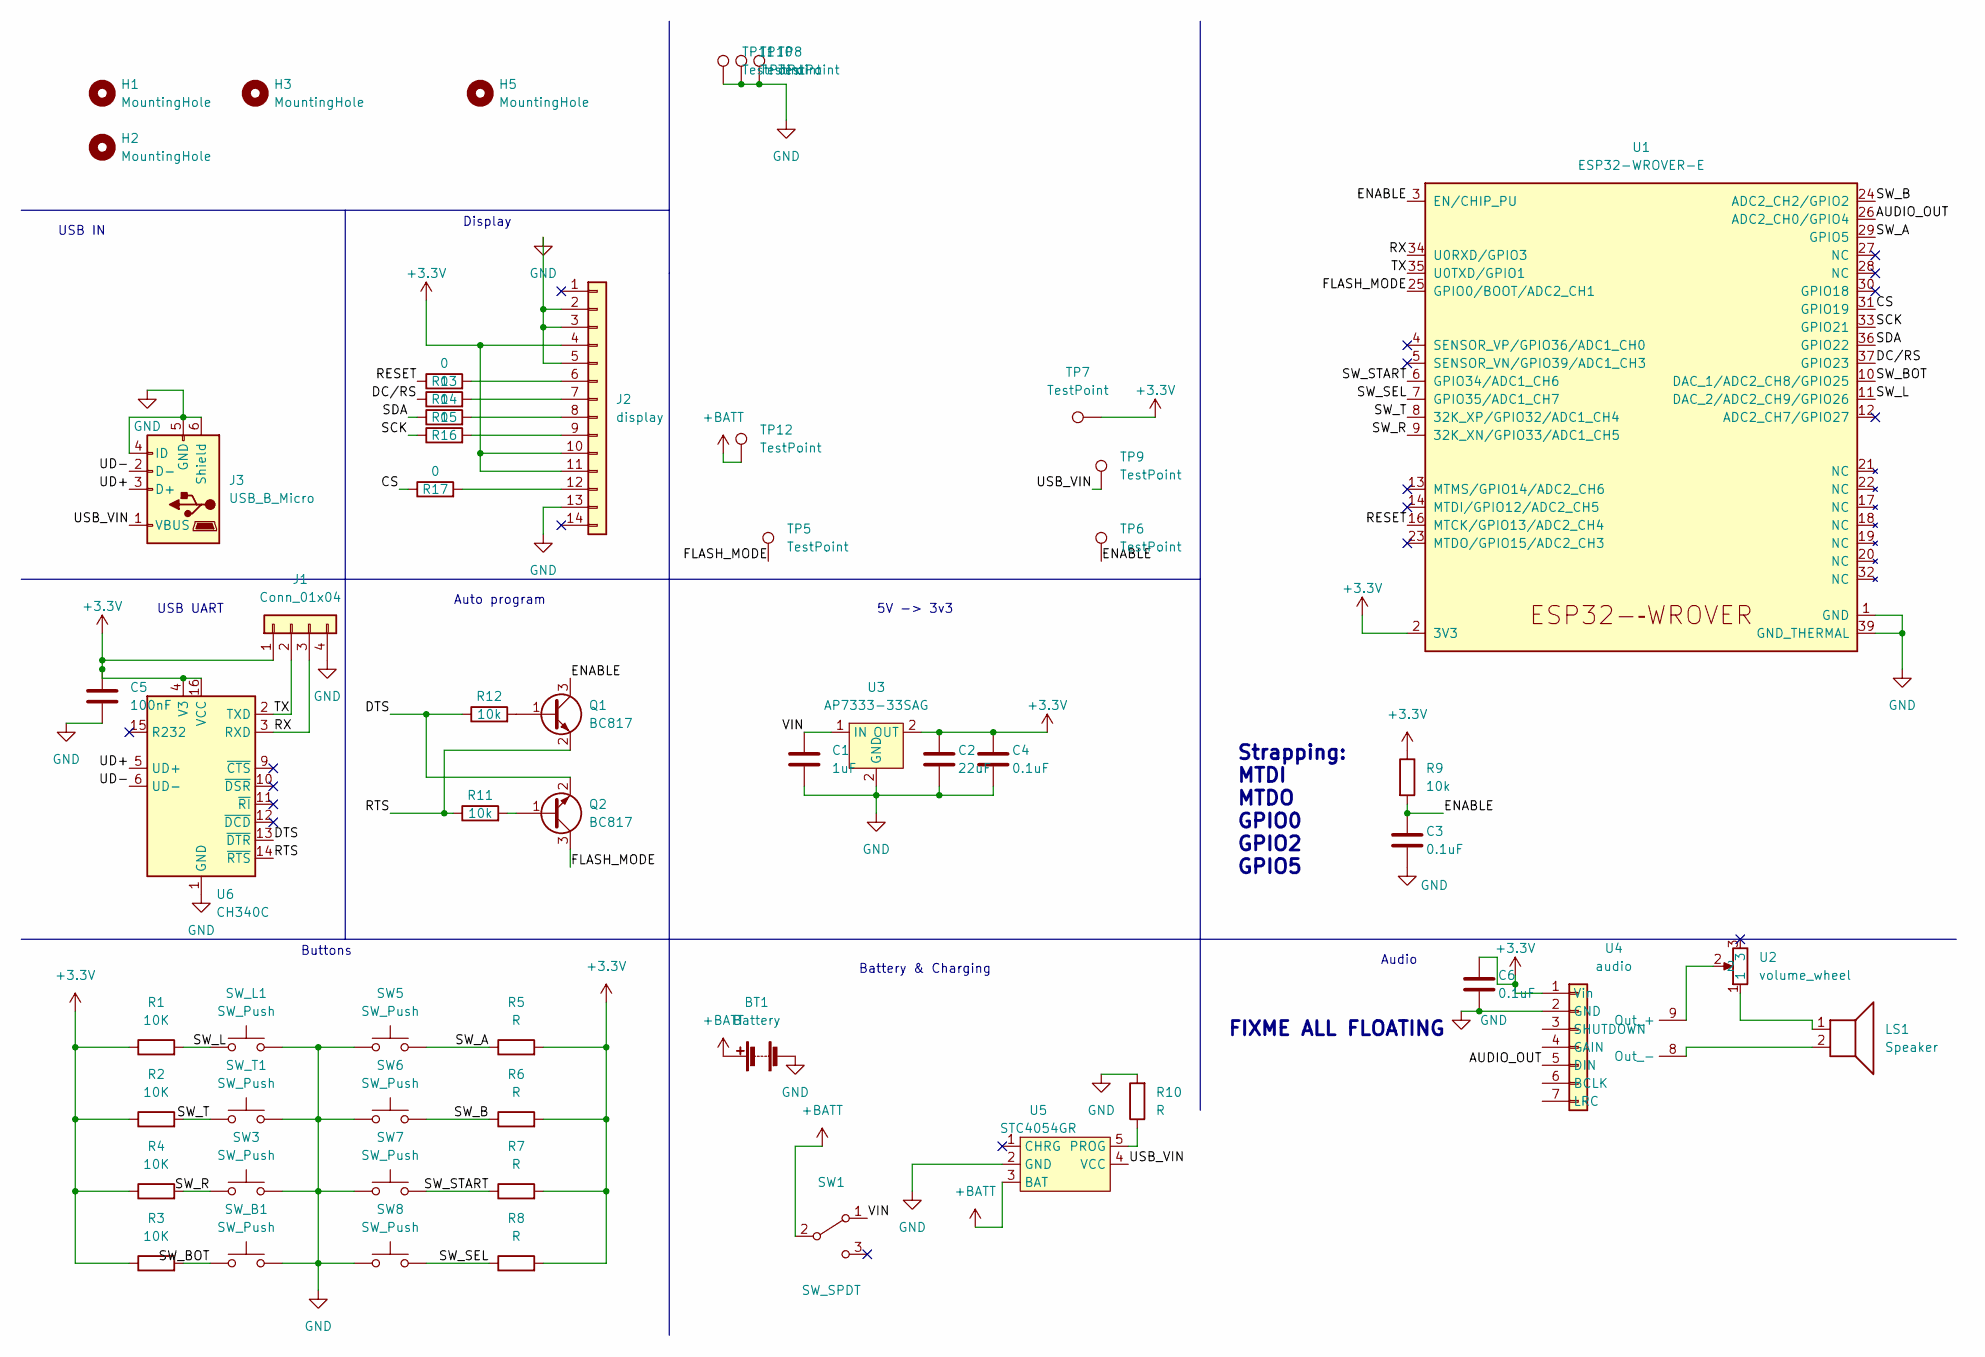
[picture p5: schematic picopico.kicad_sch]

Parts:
BT1: Battery; SM02B-SRSS-TB
C1: 1uF; C_1206_3216Metric
C2: 22uF; C_1206_3216Metric
C3, C4, C6: 0.1uF; C_1206_3216Metric
C5: 100nF; C_1206_3216Metric
H1, H2, H3, H5: MountingHole; MountingHole_2.2mm_M2
J1: Conn_01x04; PinHeader_1x04_P2.54mm_Vertical_SMD_Pin1Right
J2: display; lcd smd
J3: USB_B_Micro; USB_Micro-B_Amphenol_10103594-0001LF_Horizontal
LS1: Speaker; speaker
Q1, Q2: BC817; SOT-23
R1, R2, R3, R4: 10K; R_1206_3216Metric_Pad1.30x1.75mm_HandSolder
R5, R6, R7, R8, R10: R; R_1206_3216Metric_Pad1.30x1.75mm_HandSolder
R9, R11, R12: 10k; R_1206_3216Metric_Pad1.30x1.75mm_HandSolder
R13, R14, R15, R16, R17: 0; R_0201_0603Metric
SW1: SW_SPDT; switch_slide_OS102011MA1QN1
SW3, SW5, SW6: SW_Push; evqq2_compact
SW7, SW8: SW_Push; SW_SPST_B3U-1100P-B
SW_B1: SW_Push; evqq2_compact
SW_L1: SW_Push; evqq2_compact
SW_T1: SW_Push; evqq2_compact
TP5, TP6, TP7, TP8, TP9, TP10, TP11, TP12: TestPoint; pad
U1: ESP32-WROVER-E; ESP32-WROVER-E_ThermalVias
U2: volume_wheel; volume wheel
U3: AP7333-33SAG; SOT-23
U4: audio
U5: STC4054GR; SOT-23-5
U6: CH340C; SOIC-16_3.9x9.9mm_P1.27mm

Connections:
+BATT: BT1.1 (+), SW1.2 (B), TP12.1, U5.3 (BAT)
/AUDIO_OUT: U1.26 (ADC2_CH0/GPIO4), U4.5 (DIN)
/CS: R17.1, U1.31 (GPIO19)
/DC/RS: R14.1, U1.37 (GPIO23)
/DTS: Q2.2 (E), R12.1, U6.13 (~DTR)
/ENABLE: C3.1, Q1.3 (C), R9.2, TP6.1, U1.3 (EN/CHIP_PU)
/FLASH_MODE: Q2.3 (C), TP5.1, U1.25 (GPIO0/BOOT/ADC2_CH1)
/RESET: R13.1, U1.16 (MTCK/GPIO13/ADC2_CH4)
/RTS: Q1.2 (E), R11.1, U6.14 (~RTS)
/RX: J1.3, U1.34 (U0RXD/GPIO3), U6.3 (RXD)
/SCK: R16.1, U1.33 (GPIO21)
/SDA: R15.1, U1.36 (GPIO22)
/SW_A: R5.1, SW5.2, U1.29 (GPIO5)
/SW_B: R6.1, SW6.2, U1.24 (ADC2_CH2/GPIO2)
/SW_BOT: R3.2, SW_B1.1, U1.10 (DAC_1/ADC2_CH8/GPIO25)
/SW_L: R1.2, SW_L1.1, U1.11 (DAC_2/ADC2_CH9/GPIO26)
/SW_R: R4.2, SW3.1, U1.9 (32K_XN/GPIO33/ADC1_CH5)
/SW_SEL: R8.1, SW8.2, U1.7 (GPIO35/ADC1_CH7)
/SW_START: R7.1, SW7.2, U1.6 (GPIO34/ADC1_CH6)
/SW_T: R2.2, SW_T1.1, U1.8 (32K_XP/GPIO32/ADC1_CH4)
/TX: J1.2, U1.35 (U0TXD/GPIO1), U6.2 (TXD)
/UD+: J3.3 (D+), U6.5 (UD+)
/UD-: J3.2 (D-), U6.6 (UD-)
/USB_VIN: J3.1 (VBUS), TP9.1, U5.4 (VCC)
/VIN: C1.1, SW1.1 (A), U3.1 (IN)
unnamed: J2.6, R13.2
unnamed: J2.7, R14.2
unnamed: J2.8, R15.2
unnamed: J2.9, R16.2
unnamed: J2.12, R17.2
unnamed: LS1.1, U2.1
unnamed: LS1.2, U4.8 (Out_-)
unnamed: Q1.1 (B), R12.2
unnamed: Q2.1 (B), R11.2
unnamed: R10.1, U5.5 (PROG)
unnamed: U2.2, U4.9 (Out_+)

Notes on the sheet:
Audio
Auto program
USB UART
Buttons
Display
USB IN
Battery & Charging
Strapping: MTDI MTDO GPIO0 GPIO2 GPIO5
5V -> 3v3
FIXME ALL FLOATING

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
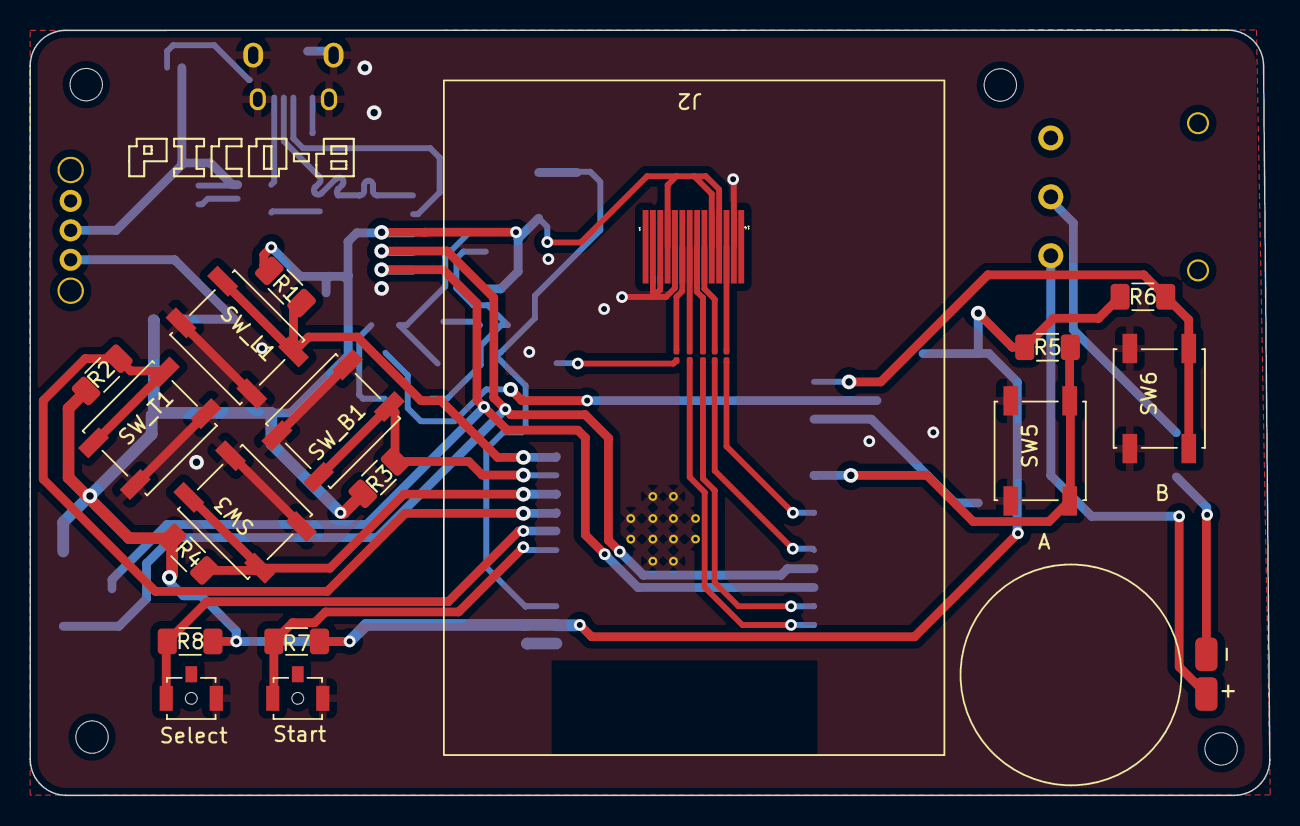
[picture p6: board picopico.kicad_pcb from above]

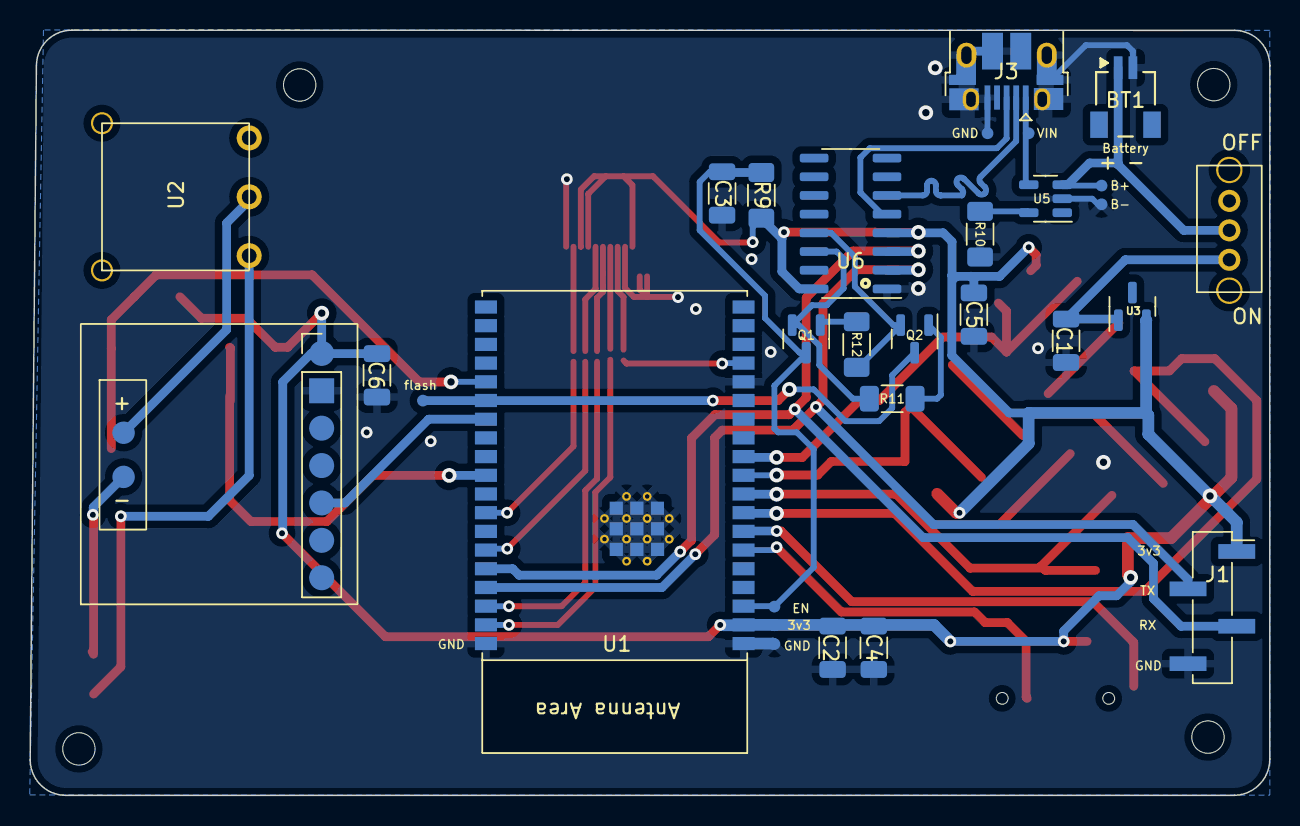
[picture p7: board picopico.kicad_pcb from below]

Board: 2 copper layers, 84.2 x 52.0 mm, 57 parts (30 on the bottom side), 38 nets.

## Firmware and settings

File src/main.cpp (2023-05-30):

#include "lua/fix32.h"
#include "lua/lua.h"
#include <stdbool.h>
#include "engine.c"
#if defined(SDL_BACKEND)
#include "sdl_backend.c"
#elif defined(PICO_BACKEND)
#include "pico_backend.c"
#elif defined(RAWDRAW_BACKEND)
#include "rawdraw_backend.c"
#elif defined(TEST_BACKEND)
#include "test_backend.c"
#elif defined(ESP_BACKEND)
//#include "esp/backend.c"
#elif defined(__3DS__)
#include "3ds_backend.cpp"
#endif


int16_t drawMenu() {
    int8_t highlighted = 0;
    uint8_t cartCount = sizeof(carts)/sizeof(GameCart);
    uint8_t cartsToShow = 3;
    bool changed = true;
    uint8_t first, last = 0;
    delay(10);
    while(!wants_to_quit) {

        if (buttons_frame[BTN_IDX_DOWN]) {
            highlighted = (highlighted + 1) % cartCount;
            changed = true;
        }

        if (buttons_frame[BTN_IDX_UP]) {
             highlighted = highlighted == 0 ? cartCount - 1 : highlighted - 1;
             changed = true;
        }

        if(changed) {
            if (carts[highlighted].label_len) {
                memcpy(&label.sprite_data, carts[highlighted].label, carts[highlighted].label_len);
            } else {
                memset(&label.sprite_data, 0x1f, sizeof(label.sprite_data));
            }
            gfx_cls(original_palette[0]);
            drawHud();
            //render_stretched(&label, 0, 0, 128, 128, 32, 0, 64, 64);
            render_stretched(&label, 0, 0, 127, 127, 16, 0, 96, 96);
            //_render(&label, 0, 0, 0, 0, -1, false, false, 128, 128);
            first = MAX(0, highlighted - cartsToShow/2);
            last = MIN(cartsToShow, cartCount);
            for(uint8_t i=0; i<last; i++) {
                uint8_t idx = i+first;
                if (idx >= cartCount) break;
                _print(carts[idx].name, carts[idx].name_len, 10, 100+i*7, highlighted == idx ? 9 : 7);
            }
            changed = false;
        }

        if (buttons[4] || buttons[5]) {
            return highlighted;
        }

		flip();
    }
    return -1;
}

int pico8() {
    bootup_time = now();
    if( !init_video() )
    {
        printf( "Failed to initialize video!\n" );
        return 1;
    }
    uint32_t init_done = now();
    printf("initializing video took %dms\n", init_done-bootup_time);

    if( !init_audio() )
    {
        printf( "Failed to initialize audio!\n" );
        return 1;
    }

    engine_init();
    init_done = now();
    printf("initializing engine took %dms\n", init_done-bootup_time);
    bootup_time = now();


    init_done = now();
    printf("initializing took %dms\n", init_done-bootup_time);


    //int16_t game = 0; // FIXME drawMenu();
    int16_t game = drawMenu();
    if (game < 0) {
        video_close();
        return 1;
    }
    gfx_cls(original_palette[0]);
    memset(buttons, 0, sizeof(buttons));
    delay(10);

    bootup_time = now();
    printf("Parsing cart %s\n", carts[game].name);
    cartParser(&carts[game]);

    printf("init lua \n");
    bool lua_ok = init_lua(carts[game].code, carts[game].code_len);
    printf("init done \n");
	if ( !lua_ok ) {
		printf( "Failed to initialize LUA!\n" );
		return 1;
		while (!wants_to_quit) {
			flip();
		}
		return 1;
	}
    init_done = now();
    printf("Parsing took %dms\n", init_done-bootup_time);

    // call _init first, in case _update / _draw are defined then
    if (_lua_fn_exists("_init")) _to_lua_call("_init");

    bool call_update = _lua_fn_exists("_update");
    bool call_update60 = _lua_fn_exists("_update60");
    bool call_draw = _lua_fn_exists("_draw");


    if (call_update) {
	fps = 30;
	ms_delay = 1000 / fps;
    } else if (call_update60) {
	fps = 60;
	ms_delay = 1000 / fps;
    } else {
	fps = 0;
	ms_delay = 0;
    }
    uint32_t update_start_time;
    uint32_t draw_start_time;

    uint32_t update_end_time;
    uint32_t draw_end_time;

    bool skip_next_render = false;
    uint16_t frame_count = 0;
    suspended = false;
    while (!wants_to_quit) {
		if(suspended) {
			delay(50);
			continue;
		}
        update_start_time = now();
        (void)update_start_time;
        (void)update_end_time; // logging is conditional, this makes the unused warning go away
        if (call_update) _to_lua_call("_update");
        if (call_update60) _to_lua_call("_update60");
        update_end_time = now();

        draw_start_time = now();
        if (call_draw && !skip_next_render) _to_lua_call("_draw");
        draw_end_time = now();

        if (draw_end_time - draw_start_time > ms_delay)
            skip_next_render = true;
        else
            skip_next_render = false;

        lua_gc(L, LUA_GCSTEP, 0);

        // printf("FE %d, FS %d, UE %d, US %d, DE %d, DS %d\n",frame_end_time, frame_start_time, update_end_time, update_start_time, draw_end_time, draw_start_time);
        // printf("Frame: %03d [U: %d, D: %03d], Remaining: %d\n", frame_end_time - frame_start_time, update_end_time - update_start_time, draw_end_time - draw_start_time, delta);
        frame_count++;
        if ((frame_count % 150) == 0) { // ~5s
            drawHud();
            draw_hud();
        }
	flip();
    }

    lua_close(L);
    video_close();
    return 0;
}

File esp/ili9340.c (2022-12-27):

#include <string.h>
#include <math.h>

#include "freertos/FreeRTOS.h"
#include "freertos/task.h"

#include <driver/spi_master.h>
#include <driver/gpio.h>
#include "esp_log.h"

#include "ili9340.h"

#define TAG "ILI9340"
#define	_DEBUG_ 0

#ifdef CONFIG_IDF_TARGET_ESP32
#define LCD_HOST HSPI_HOST
#elif defined CONFIG_IDF_TARGET_ESP32S2
#define LCD_HOST SPI2_HOST
#elif defined CONFIG_IDF_TARGET_ESP32S3
#define LCD_HOST SPI2_HOST
#elif defined CONFIG_IDF_TARGET_ESP32C3
#define LCD_HOST SPI2_HOST
#endif

//static const int GPIO_MOSI = 23;
//static const int GPIO_SCLK = 18;

static const int SPI_Command_Mode = 0;
static const int SPI_Data_Mode = 1;
//static const int TFT_Frequency = SPI_MASTER_FREQ_20M;
////static const int TFT_Frequency = SPI_MASTER_FREQ_26M;
static const int TFT_Frequency = SPI_MASTER_FREQ_40M;
////static const int TFT_Frequency = SPI_MASTER_FREQ_80M;

void spi_master_init(TFT_t * dev, gpio_num_t GPIO_MOSI, gpio_num_t GPIO_SCLK, gpio_num_t TFT_CS, gpio_num_t GPIO_DC, gpio_num_t GPIO_RESET, gpio_num_t GPIO_BL)
{
	esp_err_t ret;

	ESP_LOGI(TAG, "TFT_CS=%d",TFT_CS);
	//gpio_pad_select_gpio( TFT_CS );
	gpio_reset_pin( TFT_CS );
	gpio_set_direction( TFT_CS, GPIO_MODE_OUTPUT );
	//gpio_set_level( TFT_CS, 0 );
	gpio_set_level((gpio_num_t)TFT_CS, 1 ); // TODO this is invented from st7789

	ESP_LOGI(TAG, "GPIO_DC=%d",GPIO_DC);
	//gpio_pad_select_gpio( GPIO_DC );
	gpio_reset_pin( GPIO_DC );
	gpio_set_direction( GPIO_DC, GPIO_MODE_OUTPUT );
	gpio_set_level((gpio_num_t) GPIO_DC, 0 );

	ESP_LOGI(TAG, "GPIO_RESET=%d",GPIO_RESET);
	if ( GPIO_RESET >= 0 ) {
		//gpio_pad_select_gpio( GPIO_RESET );
		gpio_reset_pin( GPIO_RESET );
		gpio_set_direction( GPIO_RESET, GPIO_MODE_OUTPUT );
		gpio_set_level( (gpio_num_t)GPIO_RESET, 1 );
		vTaskDelay( pdMS_TO_TICKS( 1 ) );
		gpio_set_level((gpio_num_t) GPIO_RESET, 0 );
		vTaskDelay( pdMS_TO_TICKS( 5 ) );
		gpio_set_level( (gpio_num_t)GPIO_RESET, 1 );
		vTaskDelay( pdMS_TO_TICKS( 5 ) );
	}

	ESP_LOGI(TAG, "GPIO_BL=%d",GPIO_BL);
	if ( GPIO_BL >= 0 ) {
		//gpio_pad_select_gpio( GPIO_BL );
		gpio_reset_pin( GPIO_BL );
		gpio_set_direction( GPIO_BL, GPIO_MODE_OUTPUT );
		gpio_set_level((gpio_num_t) GPIO_BL, 0 );
	}

	ESP_LOGI(TAG, "GPIO_MOSI=%d",GPIO_MOSI);
	ESP_LOGI(TAG, "GPIO_CLK=%d",GPIO_SCLK);
	spi_bus_config_t buscfg = {
		.mosi_io_num = GPIO_MOSI,
		.miso_io_num = -1,
		.sclk_io_num = GPIO_SCLK,
		.quadwp_io_num = -1,
		.quadhd_io_num = -1,
        .max_transfer_sz = CONFIG_WIDTH*CONFIG_HEIGHT*2,
        .flags = 0
	};

	ret = spi_bus_initialize(LCD_HOST, &buscfg, SPI_DMA_CH_AUTO );
	ESP_LOGD(TAG, "spi_bus_initialize=%d",ret);
	assert(ret==ESP_OK);

	spi_device_interface_config_t tft_devcfg;
    memset(&tft_devcfg, 0, sizeof(tft_devcfg));
    tft_devcfg.clock_speed_hz = TFT_Frequency;
    tft_devcfg.spics_io_num = TFT_CS;
    tft_devcfg.queue_size = 1;
    tft_devcfg.mode = 0; // tried mode in 2, black screen
    tft_devcfg.flags = SPI_DEVICE_NO_DUMMY;

    spi_device_handle_t tft_handle;
	ret = spi_bus_add_device( LCD_HOST, &tft_devcfg, &tft_handle);
	ESP_LOGD(TAG, "spi_bus_add_device=%d",ret);
	assert(ret==ESP_OK);
	dev->_dc = GPIO_DC;
	dev->_bl = GPIO_BL;
	dev->_TFT_Handle = tft_handle;

}


bool spi_master_write_byte(spi_device_handle_t SPIHandle, const uint8_t* Data, size_t DataLength)
{
	spi_transaction_t SPITransaction;
	esp_err_t ret;

    memset( &SPITransaction, 0, sizeof( spi_transaction_t ) );
    SPITransaction.length = DataLength * 8;
    SPITransaction.tx_buffer = Data;
#if 0
    ret = spi_device_transmit( SPIHandle, &SPITransaction );
#else
    ret = spi_device_polling_transmit( SPIHandle, &SPITransaction );
#endif
    assert(ret==ESP_OK); 

	return true;
}

bool spi_master_write_comm_byte(TFT_t * dev, uint8_t cmd)
{
	static uint8_t Byte = 0;
	Byte = cmd;
	gpio_set_level((gpio_num_t) dev->_dc, SPI_Command_Mode );
	return spi_master_write_byte( dev->_TFT_Handle, &Byte, 1 );
}

bool spi_master_write_comm_word(TFT_t * dev, uint16_t cmd)
{
	static uint8_t Byte[2];
	Byte[0] = (cmd >> 8) & 0xFF;
	Byte[1] = cmd & 0xFF;
	gpio_set_level( (gpio_num_t)dev->_dc, SPI_Command_Mode );
	return spi_master_write_byte( dev->_TFT_Handle, Byte, 2 );
}


bool spi_master_write_data_byte(TFT_t * dev, uint8_t data)
{
	static uint8_t Byte = 0;
	Byte = data;
	gpio_set_level((gpio_num_t) dev->_dc, SPI_Data_Mode );
	return spi_master_write_byte( dev->_TFT_Handle, &Byte, 1 );
}


bool spi_master_write_data_word(TFT_t * dev, uint16_t data)
{
	static uint8_t Byte[2];
	Byte[0] = (data >> 8) & 0xFF;
	Byte[1] = data & 0xFF;
	gpio_set_level((gpio_num_t) dev->_dc, SPI_Data_Mode );
	return spi_master_write_byte( dev->_TFT_Handle, Byte, 2);
}


void delayMS(int ms) {
	int _ms = ms + (portTICK_PERIOD_MS - 1);
	TickType_t xTicksToDelay = _ms / portTICK_PERIOD_MS;
	ESP_LOGD(TAG, "ms=%d _ms=%d portTICK_PERIOD_MS=%d xTicksToDelay=%d",ms,_ms,portTICK_PERIOD_MS,xTicksToDelay);
	vTaskDelay(xTicksToDelay);
}


void lcdWriteRegisterByte(TFT_t * dev, uint8_t addr, uint16_t data)
{
	spi_master_write_comm_byte(dev, addr);
	spi_master_write_data_word(dev, data);
}
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

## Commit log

2022-04-30 working pico
2022-04-30 send entire buffer in one write to display; use time in ms to calculate framedeltas
2022-04-30 fix font parsing in pico (missing null byte at the end of data); "improve" colors
    [pico_backend.c]
2022-05-01 reset into usb mode on pressing "r" over usb-uart; add basic perf metric
    [pico_backend.c]
2022-05-01 implement camera
2022-05-03 check for errors on lua init; wait for re-flash input on failure
    [main.cpp]
2022-05-03 add buttons A and B
2022-05-04 special-case the count of "11" repetitions to be 0xFF to not confuse the parser with what looks like stray "\n"s
2022-05-04 add notes on faster SPI clock speed
2022-05-04 add some hacks in put_pixel to not crash program; need to bounds-check before probably
    [pico_backend.c]
2022-05-04 implement palt, pset, sget, cartdata, dset, dget, camera and add a stub for menuitem
2022-05-04 hack for non ascii X/O print
2022-05-04 allow quitting SDL on PC while debugging lua crashes
    [main.cpp]
2022-05-04 allow parallel build directories based on PICO var
2022-05-04 call reset transparency on plt and pal
    [main.cpp]
2022-05-04 consider camera for pset and circfill
2022-05-05 trigger a GC step per frame
2022-05-08 add notes on ESP32, memory and jit
2022-05-08 remove superfluous printh
2022-05-11 add st7735 drivers
2022-05-11 use ili driver
2022-05-11 fix build so all platforms can build at the same time
    [backend.c, data.h, main.cpp]
2022-05-13 convert to fixed point math (only triangle wave)
    [synth.c, synth.h]
2022-05-14 transfer audio via a task using dma
2022-05-14 re-organize audio to fill buffers on callback; similar to how the DMA requests are executed on ESP32
2022-05-14 set up audio with dma for esp
2022-05-15 add notes on SFX dma
2022-05-15 Fix buffer overflow on audio
    Shouldn't add the whole `SAMPLES_PER_DURATION` -- each iteration adds an
    extra "1" to this count; so should add `SAMPLES_PER_DURATION-1` instead
2022-06-06 split print so it can be called directly from AOT
2022-10-02 add board
    [board.kicad_sch]
2022-10-15 board stuff
    [board.kicad_sch]
2022-10-15 Revert "update sdk"
    This reverts commit 3a7c0a7248e9e47df38a72b0bb6d1e7b8050b992.
    [backend.c, ili9340.c]
2022-10-16 add board stuff
    [board.kicad_sch, picopico.kicad_pcb, picopico.kicad_sch]
2022-10-16 update board
    [picopico.kicad_pcb, picopico.kicad_sch]
2022-10-19 board update
    [picopico.kicad_pcb]
2022-12-26 update config, fix pin definitions
2022-12-28 flush prints
2022-12-29 add note on shorthand print
2022-12-29 implement flip; refactor code to be flip-based
    [main.cpp]
2022-12-31 run lua_gc passes per frame
2022-12-31 Add bounds check on gfx_line
    Was overwriting `frame_end_time`, making some sleeps randomly take very
    long
2022-12-31 enable addr sanitizer, fix many bugs
    [main.cpp]
2023-01-01 bugfixes for esp32 from refactoring
    [backend.c, main.cpp]
2023-01-01 move hardcoded pin settings to kconfig
2023-02-05 rewire board
    [picopico.kicad_pcb, picopico.kicad_sch]
2023-03-12 observe camera x/y on print
2023-03-12 implement \f in print for fg color
2023-03-12 print special wide and tall chars
2023-03-12 add support for printing arrows
2023-03-12 support background colors on print
2023-03-13 support \n and better bg color for print
2023-03-13 fix bg color on print
2023-03-15 make line observe camera
2023-04-12 implement print for heart font
2023-05-23 mostly handle input; fix now() calculation
    [main.cpp]
2023-05-27 allow scaling factor & create rendering thread
2023-05-27 remove threads, crash on console
2023-05-28 constant for button indices
2023-06-05 make work with esp32
2023-06-05 add boardv2 stuff
